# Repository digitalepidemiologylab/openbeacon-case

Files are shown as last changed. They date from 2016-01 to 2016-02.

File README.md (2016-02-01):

# openbeacon-case
##OpenBeacon proximity tag case##

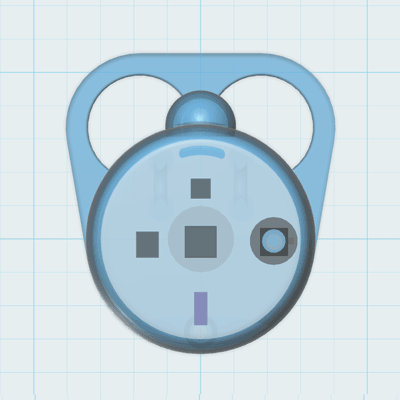
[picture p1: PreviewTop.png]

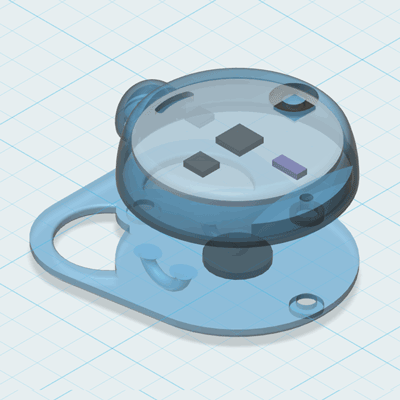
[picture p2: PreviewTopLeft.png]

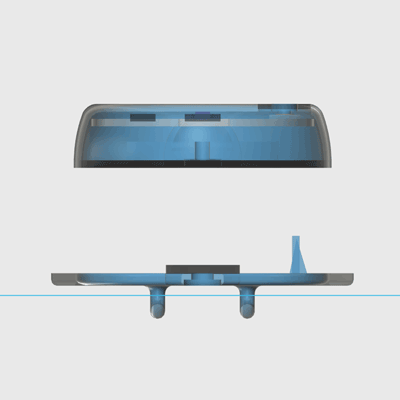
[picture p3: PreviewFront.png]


Taking part in a study involving 70 participants, and having no available case fitting our needs for the proximity tag we'd use, we decided to design our own.

Technical details about the tag can be found on [OpenBeacon.org](http://get.openbeacon.org/device.html#download).

Our main challenges were:

- **Maximize the compliance of hospital personals and patients taking part in our planned study.** To help achieve the best possible compliance, the case should have a dedicated space to hold a sticker with the hospital logo, and should be nice-looking of course.
- **Have a tag that could be hooked to a lanyard or hooked to a safety pin.**
- **The case should be relatively easy to open and close, but not too much so.** Easy for battery replacement or whenever direct access to the PCB is needed, but not so easy that no tool is needed.
- **The case should be somewhat waterproof.**
- **The button on the PCB should be accessible.**
- **Take advantage of the full capabilities of the tag.** One of the requirements was that the tag point towards the front and stay so.
- **Find the right 3D design tool.** We are no 3D designers, we work on Macs and we wanted fast results, so after reviewing a few softwares, we chose [123d Design](http://www.123dapp.com/design) by AUTODESK. Its learning curve seemed the best of all reviewed tools, the examples looked great, it can export .STL files used by 3D printers and it's free.

We didn't need a case:

- that could resist huge shocks
- that could be used for years

**3D-Printing**

The case was printed at the [Centre universitaire d'informatique](http://www.cui.unige.ch/en/), Geneva University, by a Stratasys [Objet260](http://www.stratasys.com/3d-printers/design-series/objet260-connex3). Thanks to Daniel Agulleiro for his great advices and help.

The printer used allows printing several materials at once, with different softness and color. All materials are polymerized together, giving absolutely great results. All parts are printed mate (as opposed to glossy).

Materials used:
- White parts: RGD515 + RGD531 (Ivory)
- Button rubber part: Tango Black+ xxxxx60
- All other black parts: Tango Black+ xxxxx40

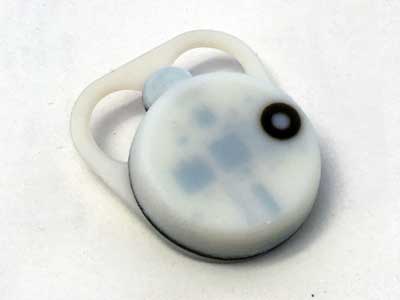
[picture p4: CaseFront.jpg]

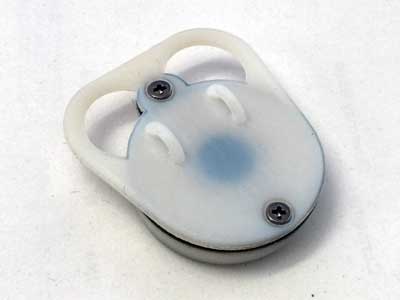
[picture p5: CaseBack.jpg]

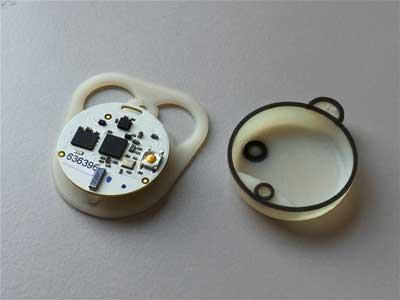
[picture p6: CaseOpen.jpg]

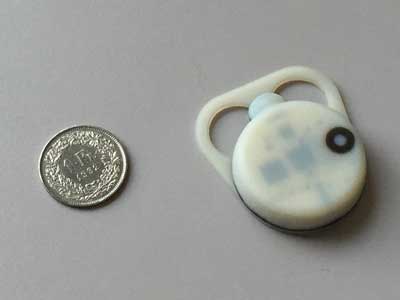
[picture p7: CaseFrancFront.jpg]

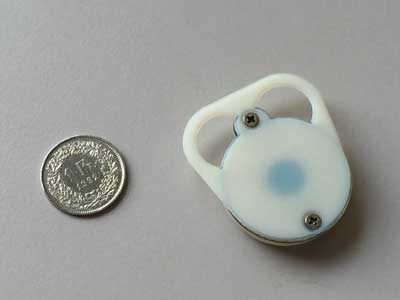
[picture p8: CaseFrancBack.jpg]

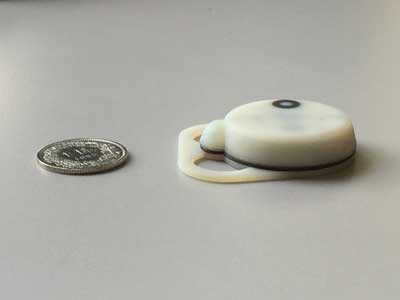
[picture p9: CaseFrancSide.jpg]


Cases are printed in rows. Time to print is roughly proportional to the number of rows needed on the printer board times the height of the highest object (in mm) x 5. In our case, a row like this one:

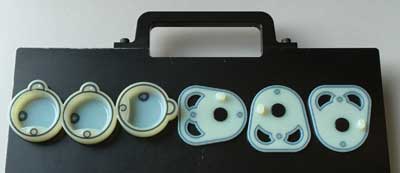
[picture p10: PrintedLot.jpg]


...took around 1 x 10 mm x 5 = 50 minutes to print.

Each part must then be cleaned.

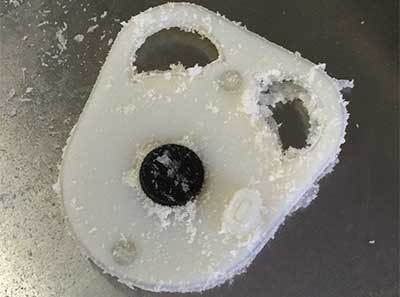
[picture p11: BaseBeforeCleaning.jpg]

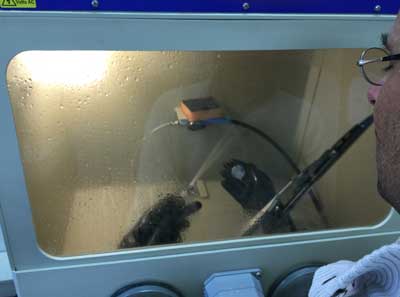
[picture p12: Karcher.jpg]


**Signal attenuation**

A rapid set of test measurements done at the [ISI Foundation](http://www.isi.it) in Torino, with and without the case, seemed to show that, despite being measurable, the signal attenutation by the case would not affect the quality of the interaction measurements.

**Waterproof?**

The case was hold for one minute under 15 cm of water. We then opened it and found no trace of water inside. That seemed enough for our needs.

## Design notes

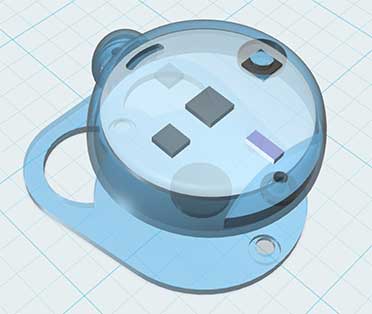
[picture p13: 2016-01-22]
Preview.jpg

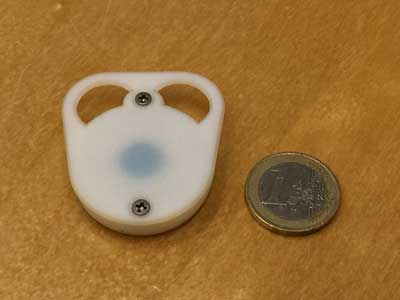
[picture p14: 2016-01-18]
CaseEuroBack.jpg

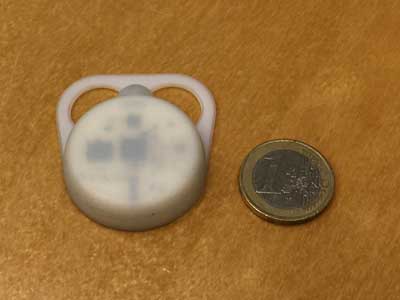
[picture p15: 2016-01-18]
CaseEuroFront.jpg

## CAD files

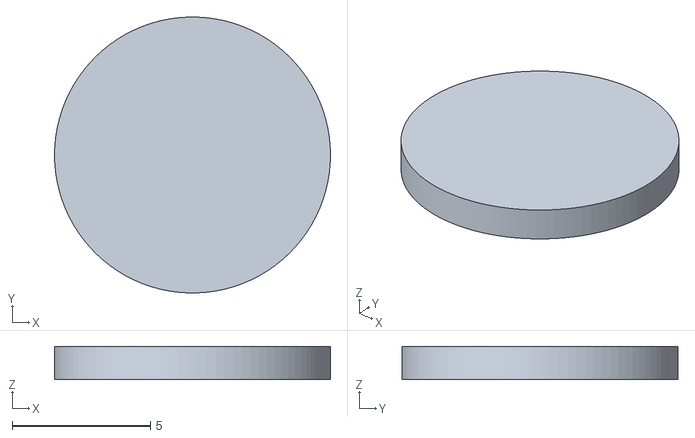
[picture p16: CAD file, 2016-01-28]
Exports/Base-caoutchouc.stl
10.00 x 9.99 x 1.20

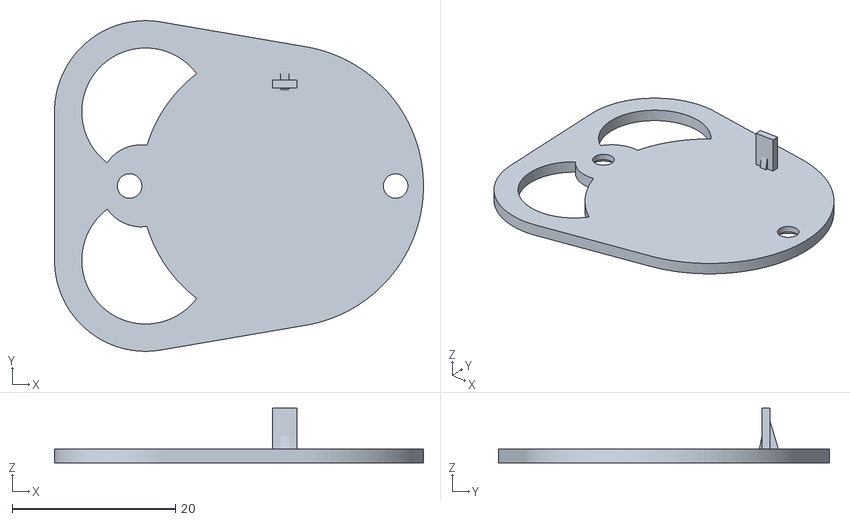
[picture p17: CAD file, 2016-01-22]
Exports/Base.stl
45.2 x 40.5 x 6.67

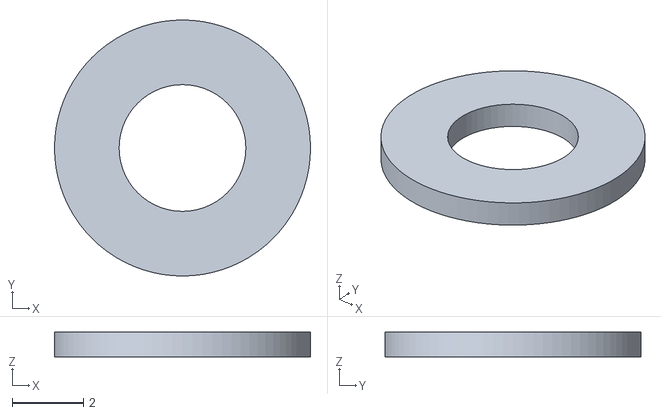
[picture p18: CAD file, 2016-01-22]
Exports/Top-bouton-caoutchouc.stl
7.20 x 7.20 x 0.7

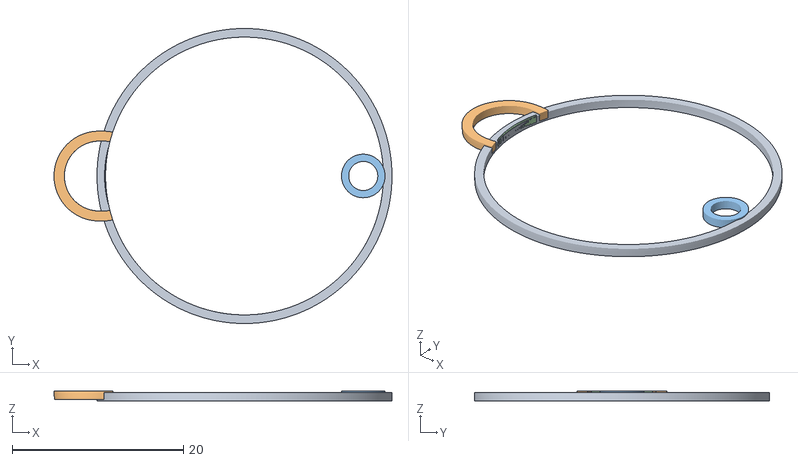
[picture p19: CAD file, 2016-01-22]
Exports/Top-caoutchouc.stl
39.5 x 34.5 x 1.21

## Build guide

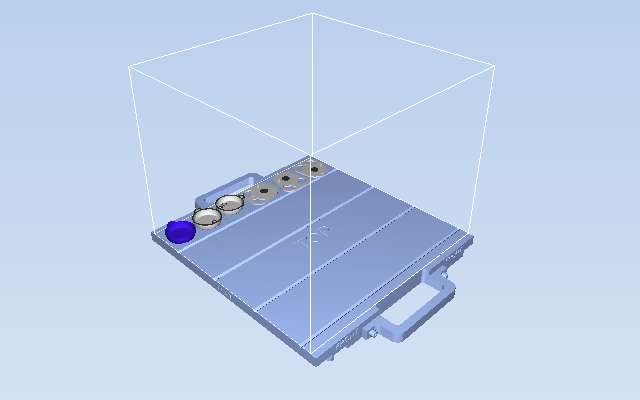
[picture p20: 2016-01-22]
Exports/Print.bmp

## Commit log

2016-01-15 OpenBeaconTagCase.123dx is our first case design, targeted at holding the tag described in OpenBeacon-Proximity-Tag-BL_PCB-3.PDF (downloaded from http://get.openbeacon.org/device.html#download on Jan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
2016-01-18 Added pictures with € coin
2016-01-20 Top modified to allow pressing the board button. Rough PCB added.
2016-01-22 Added button and way to make the case waterproof. This is a draft only, still has to be printed and tested.
2016-01-22 Fixed picot position below button
2016-01-22 Added rubber band to fix obvious leaks (case waterproof was not waterproof). Other minor tweaks.
2016-01-22 Added STL files
    [Base-caoutchouc.stl, Base.stl, Top-bouton-caoutchouc.stl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]
2016-01-22 Added files exported by printer software.
2016-01-22 Added pics for waterproof case with button
2016-01-22 Added printed lot + cleaning pictures
2016-01-26 Added loops for safety pin
2016-01-28 Brought rear loops a little closer to median line
    [Base-caoutchouc.stl]
